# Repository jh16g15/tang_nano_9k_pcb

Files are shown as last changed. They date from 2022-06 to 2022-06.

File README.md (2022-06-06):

# tang_nano_9k_pcb
Sipeed Tang Nano 9K  Carrier board design (WIP)

This board is designed to add extra interfaces to the Tang Nano 9K, such as:

- SPI Ethernet (W5500)
- Trackball
- PS/2 Keyboard
- Audio (I2S DAC)

Mini-DIN6 footprint (PS/2) provided by
https://github.com/4x1md/kicad_libraries/tree/master/Custom_Footprints.pretty

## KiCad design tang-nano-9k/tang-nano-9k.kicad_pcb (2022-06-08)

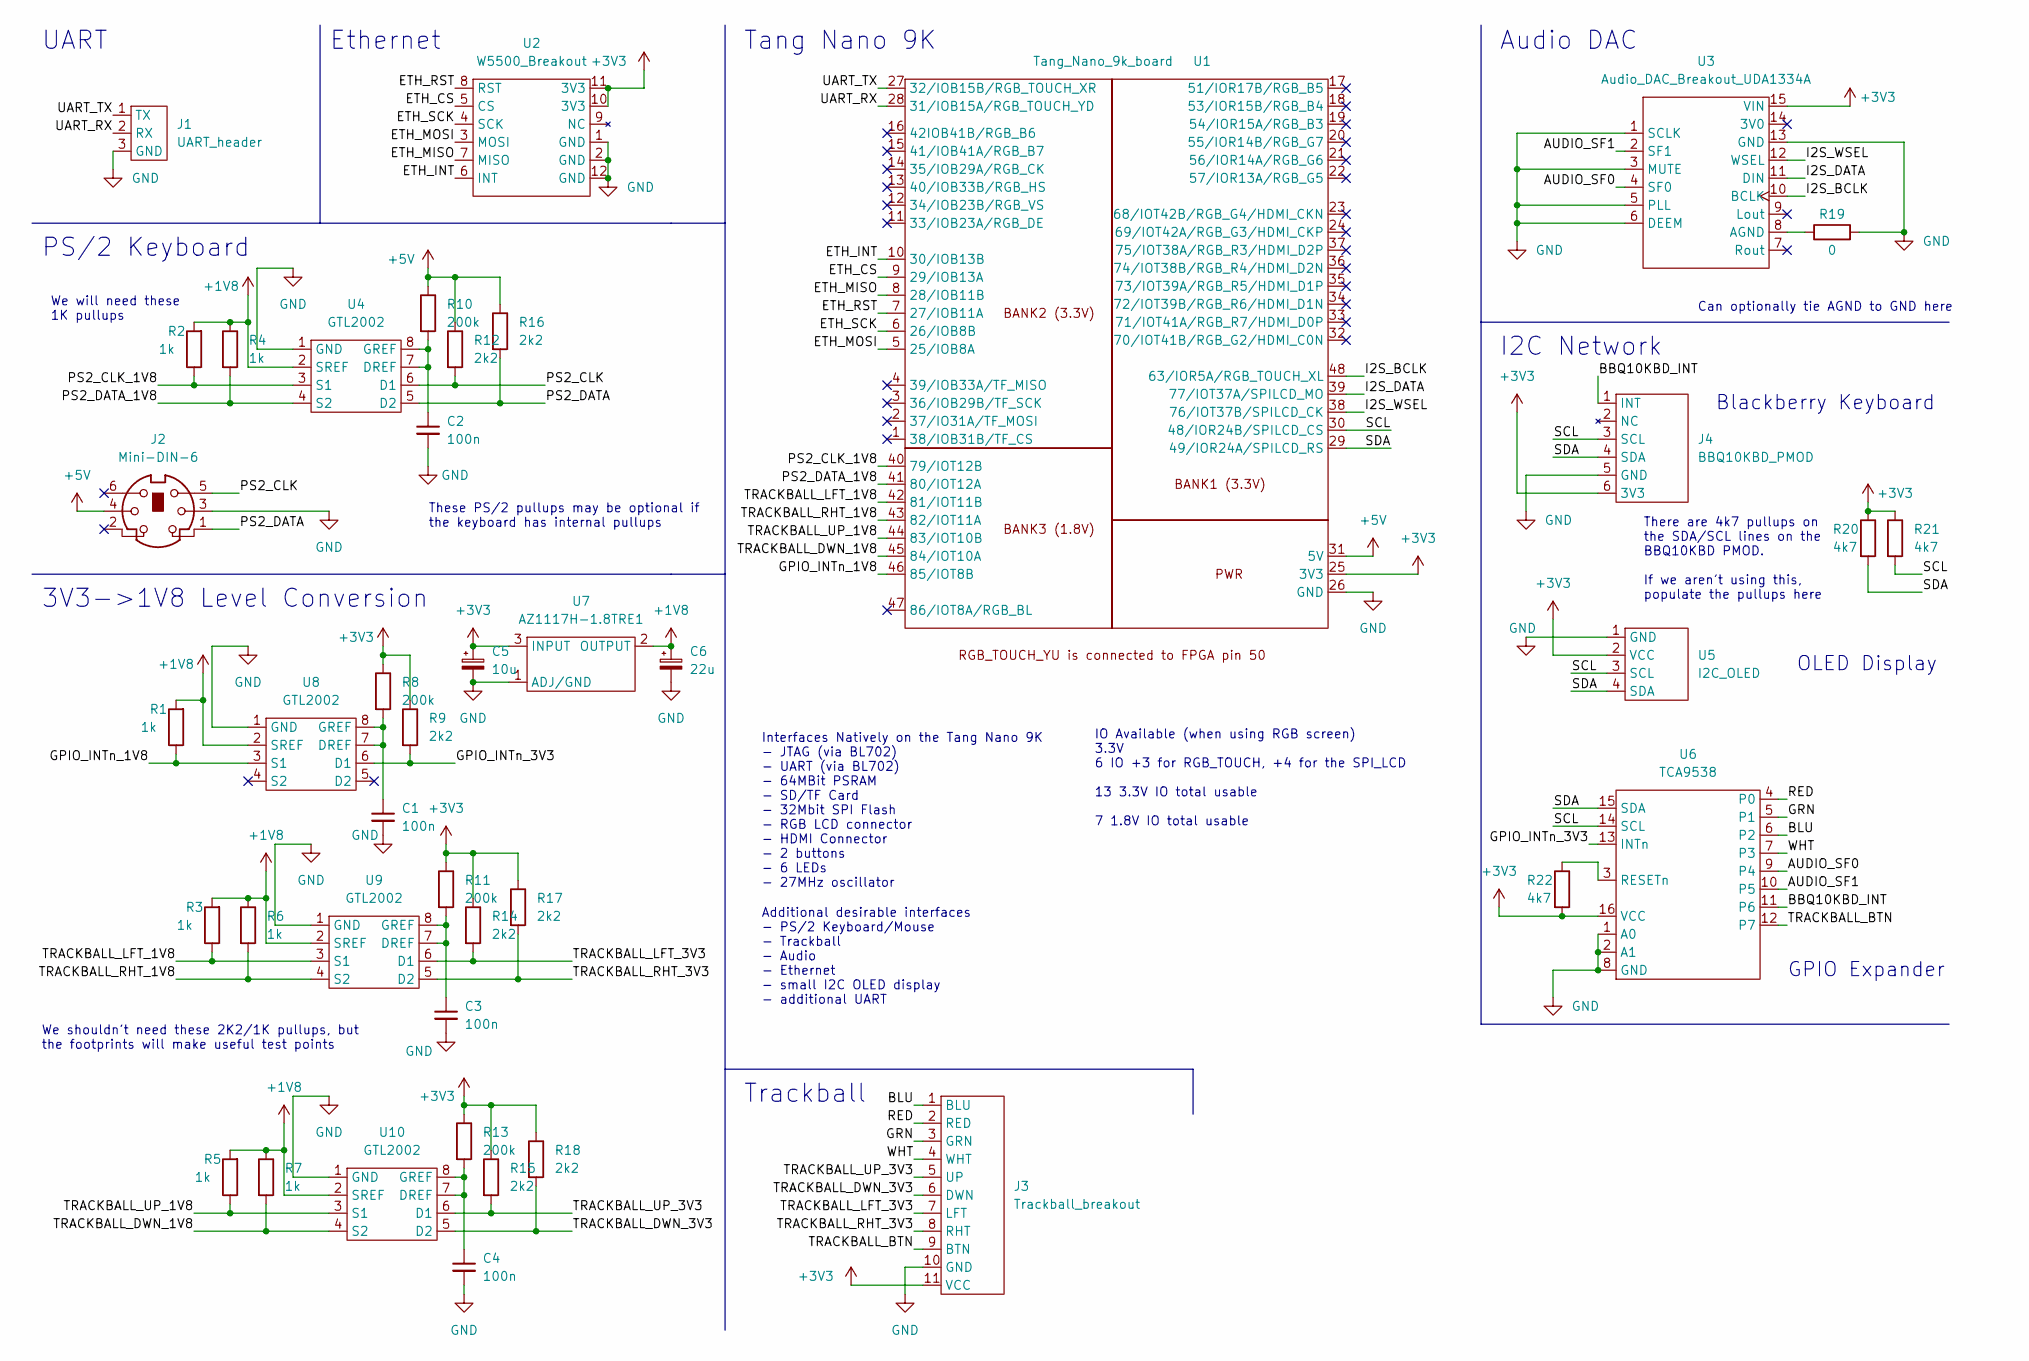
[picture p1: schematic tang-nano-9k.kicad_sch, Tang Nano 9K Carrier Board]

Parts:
C1, C2, C3, C4: 100n; C_Disc_D3.8mm_W2.6mm_P2.50mm
C5: 10u; CP_Radial_D5.0mm_P2.00mm
C6: 22u; CP_Radial_D5.0mm_P2.00mm
J1: UART_header; PinHeader_1x03_P2.54mm_Vertical
J2: Mini-DIN-6; Connector_Mini-DIN_Female_6Pin_2rows
J3: Trackball_breakout
J4: BBQ10KBD_PMOD; PinHeader_1x06_P2.54mm_Horizontal
R1, R2, R3, R4, R5, R6, R7: 1k; R_Axial_DIN0207_L6.3mm_D2.5mm_P10.16mm_Horizontal
R8, R10, R11, R13: 200k; R_Axial_DIN0207_L6.3mm_D2.5mm_P10.16mm_Horizontal
R9, R12, R14, R15, R16, R17, R18: 2k2; R_Axial_DIN0207_L6.3mm_D2.5mm_P10.16mm_Horizontal
R19: 0; R_Axial_DIN0204_L3.6mm_D1.6mm_P5.08mm_Horizontal
R20, R21, R22: 4k7; R_Axial_DIN0207_L6.3mm_D2.5mm_P10.16mm_Horizontal
U1: Tang_Nano_9k_board; Tang Nano 9K
U2: W5500_Breakout
U3: Audio_DAC_Breakout_UDA1334A; UDA1334_Breakout
U4, U8, U9, U10: GTL2002; TSSOP-8_3x3mm_P0.65mm
U5: I2C_OLED; i2c_oled_128x64
U6: TCA9538; SSOP-16_5.3x6.2mm_P0.65mm
U7: AZ1117H-1.8TRE1; SOT-223-3_TabPin2

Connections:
+1V8: C6.1, R1.2, R2.2, R3.2, R4.1, R5.2, R6.1, R7.1, U4.2 (SREF), U7.2 (OUTPUT), U8.2 (SREF), U9.2 (SREF), U10.2 (SREF)
+3V3: C5.1, J3.11 (VCC), J4.6 (3V3), R8.1, R9.1, R11.1, R13.1, R14.1, R15.1, R17.1, R18.1, R20.1, R21.1, R22.2, U1.25 (3V3), U2.10 (3V3), U2.11 (3V3), U3.15 (VIN), U5.2 (VCC), U6.16 (VCC), U7.3 (INPUT)
+5V: J2.4, R10.1, R12.1, R16.1, U1.31 (5V)
/AUDIO_SF0: U3.4 (SF0), U6.9 (P4)
/AUDIO_SF1: U3.2 (SF1), U6.10 (P5)
/BBQ10KBD_INT: J4.1 (INT), U6.11 (P6)
/BLU: J3.1 (BLU), U6.6 (P2)
/ETH_CS: U1.9 (29/IOB13A), U2.5 (CS)
/ETH_INT: U1.10 (30/IOB13B), U2.6 (INT)
/ETH_MISO: U1.8 (28/IOB11B), U2.7 (MISO)
/ETH_MOSI: U1.5 (25/IOB8A), U2.3 (MOSI)
/ETH_RST: U1.7 (27/IOB11A), U2.8 (RST)
/ETH_SCK: U1.6 (26/IOB8B), U2.4 (SCK)
/GPIO_INTn_1V8: R1.1, U1.46 (85/IOT8B), U8.3 (S1)
/GPIO_INTn_3V3: R9.2, U6.13 (INTn), U8.6 (D1)
/GRN: J3.3 (GRN), U6.5 (P1)
/I2S_BCLK: U1.48 (63/IOR5A/RGB_TOUCH_XL), U3.10 (BCLK)
/I2S_DATA: U1.39 (77/IOT37A/SPILCD_MO), U3.11 (DIN)
/I2S_WSEL: U1.38 (76/IOT37B/SPILCD_CK), U3.12 (WSEL)
/PS2_CLK: J2.5, R12.2, U4.6 (D1)
/PS2_CLK_1V8: R2.1, U1.40 (79/IOT12B), U4.3 (S1)
/PS2_DATA: J2.1, R16.2, U4.5 (D2)
/PS2_DATA_1V8: R4.2, U1.41 (80/IOT12A), U4.4 (S2)
/RED: J3.2 (RED), U6.4 (P0)
/SCL: J4.3 (SCL), R21.2, U1.30 (48/IOR24B/SPILCD_CS), U5.3 (SCL), U6.14 (SCL)
/SDA: J4.4 (SDA), R20.2, U1.29 (49/IOR24A/SPILCD_RS), U5.4 (SDA), U6.15 (SDA)
/TRACKBALL_BTN: J3.9 (BTN), U6.12 (P7)
/TRACKBALL_DWN_1V8: R7.2, U1.45 (84/IOT10A), U10.4 (S2)
/TRACKBALL_DWN_3V3: J3.6 (DWN), R18.2, U10.5 (D2)
/TRACKBALL_LFT_1V8: R3.1, U1.42 (81/IOT11B), U9.3 (S1)
/TRACKBALL_LFT_3V3: J3.7 (LFT), R14.2, U9.6 (D1)
/TRACKBALL_RHT_1V8: R6.2, U1.43 (82/IOT11A), U9.4 (S2)
/TRACKBALL_RHT_3V3: J3.8 (RHT), R17.2, U9.5 (D2)
/TRACKBALL_UP_1V8: R5.1, U1.44 (83/IOT10B), U10.3 (S1)
/TRACKBALL_UP_3V3: J3.5 (UP), R15.2, U10.6 (D1)
/UART_RX: J1.2 (RX), U1.28 (31/IOB15A/RGB_TOUCH_YD)
/UART_TX: J1.1 (TX), U1.27 (32/IOB15B/RGB_TOUCH_XR)
/WHT: J3.4 (WHT), U6.7 (P3)
GND: C1.2, C2.2, C3.2, C4.2, C5.2, C6.2, J1.3 (GND), J2.3, J3.10 (GND), J4.5 (GND), R19.2, U1.26 (GND), U2.1 (GND), U2.2 (GND), U2.12 (GND), U3.1 (SCLK), U3.3 (MUTE), U3.5 (PLL), U3.6 (DEEM), U3.13 (GND), U4.1 (GND), U5.1 (GND), U6.1 (A0), U6.2 (A1), U6.8 (GND), U7.1 (ADJ/GND), U8.1 (GND), U9.1 (GND), U10.1 (GND)
unnamed: C1.1, R8.2, U8.7 (DREF), U8.8 (GREF)
unnamed: C2.1, R10.2, U4.7 (DREF), U4.8 (GREF)
unnamed: C3.1, R11.2, U9.7 (DREF), U9.8 (GREF)
unnamed: C4.1, R13.2, U10.7 (DREF), U10.8 (GREF)
unnamed: R19.1, U3.8 (AGND)
unnamed: R22.1, U6.3 (RESETn)

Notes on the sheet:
We will need these 1K pullups
There are 4k7 pullups on the SDA/SCL lines on the BBQ10KBD PMOD. If we aren't using this, populate the pullups here
Audio DAC
IO Available (when using RGB screen) 3.3V 6 IO +3 for RGB_TOUCH, +4 for the SPI_LCD 13 3.3V IO total usable 7 1.8V IO total usable
Tang Nano 9K
We shouldn't need these 2K2/1K pullups, but the footprints will make useful test points
These PS/2 pullups may be optional if the keyboard has internal pullups
PS/2 Keyboard
Additional desirable interfaces - PS/2 Keyboard/Mouse - Trackball - Audio - Ethernet - small I2C OLED display - additional UART
Ethernet
Interfaces Natively on the Tang Nano 9K - JTAG (via BL702) - UART (via BL702) - 64MBit PSRAM - SD/TF Card - 32Mbit SPI Flash - RGB LCD connector - HDMI Connector - 2 buttons - 6 LEDs - 27MHz oscillator
GPIO Expander
Can optionally tie AGND to GND here
Trackball
UART
I2C Network
OLED Display
3V3->1V8 Level Conversion
Blackberry Keyboard

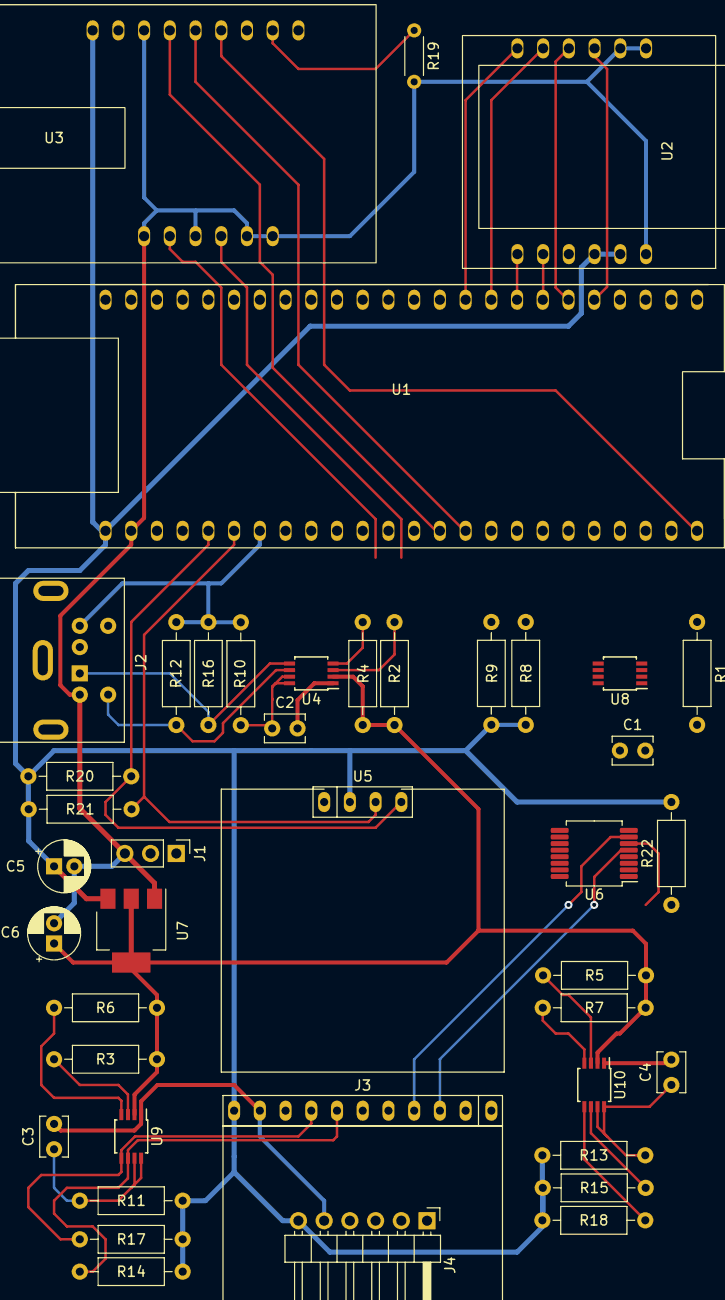
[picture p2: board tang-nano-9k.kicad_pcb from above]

Board: 2 copper layers, 42 parts (0 on the bottom side), 45 nets.

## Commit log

2022-06-05 Updated schematic
    [tang-nano-9k.kicad_sch]
2022-06-05 fixed UDA1334 connections and added NC to unused pins across the schematic
    [tang-nano-9k.kicad_sch]
2022-06-06 updated schematic with footprints
    [tang-nano-9k.kicad_pcb, tang-nano-9k.kicad_sch]
2022-06-08 Added pullups to GPIO expander INTn pin Initial placement and partial routing
    [tang-nano-9k.kicad_pcb, tang-nano-9k.kicad_sch]
